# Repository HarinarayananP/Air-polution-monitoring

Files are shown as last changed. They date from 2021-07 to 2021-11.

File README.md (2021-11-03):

# Polmo - Air Pollution Monitoring System


 
 
 

POLMO is a low cost IoT based real time air pollution monitoring system. It uses advanced sensing technologies to collect pollution information from the real world sensors and provides real time data visualization, machine learning based air quality prediction, warning information for human beings, animals, and plants due to air pollution.
## Contents

- [Polmo - Air Pollution Monitoring System](#polmo---air-pollution-monitoring-system)
  - [Contents](#contents)
  - [Short description](#short-description)
    - [What's the problem?](#whats-the-problem)
    - [How can technology help?](#how-can-technology-help)
    - [The idea](#the-idea)
  - [Demo video](#demo-video)
  - [The architecture](#the-architecture)
  - [Long description](#long-description)
  - [Project roadmap](#project-roadmap)
  - [Getting started](#getting-started)
  - [Live demo](#live-demo)
  - [Applications](#applications)
    - [Mesh Network - Simple application](#mesh-network---simple-application)
    - [Mesh Network - Vehicle Traffic](#mesh-network---vehicle-traffic)
  - [Built with](#built-with)
  - [Contributing](#contributing)
  - [Authors](#authors)
  - [License](#license)
  - [Acknoledgement](#acknoledgement)

## Short description

### What's the problem?

Air pollution adversely affects human health, plant life, and agricultural crop production. Agricultural crops can be injured when exposed to high concentrations of various air pollutants. In a recent study, researchers have analysed 30 years of data on yields of wheat and rice alongside data on air pollution and climate in India and concluded that significant decreases in yield could be attributed to air pollutants.

### How can technology help?

Regular monitoring and controlling air pollution leads to increased yield from agricultural and livestock products. The warning can be given to farmers using pollution related predictions, precautions can be taken to protect plants, plan for the right cultivation time to get more yield.  There is an increased demand for localized IoT enabled automated air pollution monitoring systems which provide air pollution related information for people through an easy interface.  For realizing such a system gas sensors with advanced sensing technologies, IoT, cloud computing, and machine learning can be Incorporated.

### The idea

Developing and deploying low cost, low power, quicker, and real time air pollution monitoring system at pollution affected area. For this, array sensor nodes are developed by incorporating major air pollutants sensors and NodeMCU.  This embedded system uploads the air pollution data to the IBM Watson IoT cloud over Wi-Fi protocol. 

## Demo video

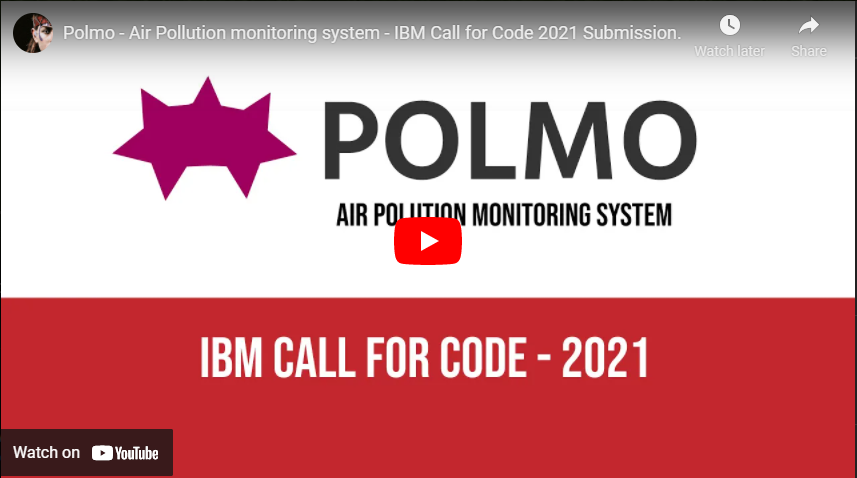
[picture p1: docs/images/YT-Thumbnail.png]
Watch the video (https://www.youtube.com/watch?v=G5Q1Tb0h1tY)


## The architecture

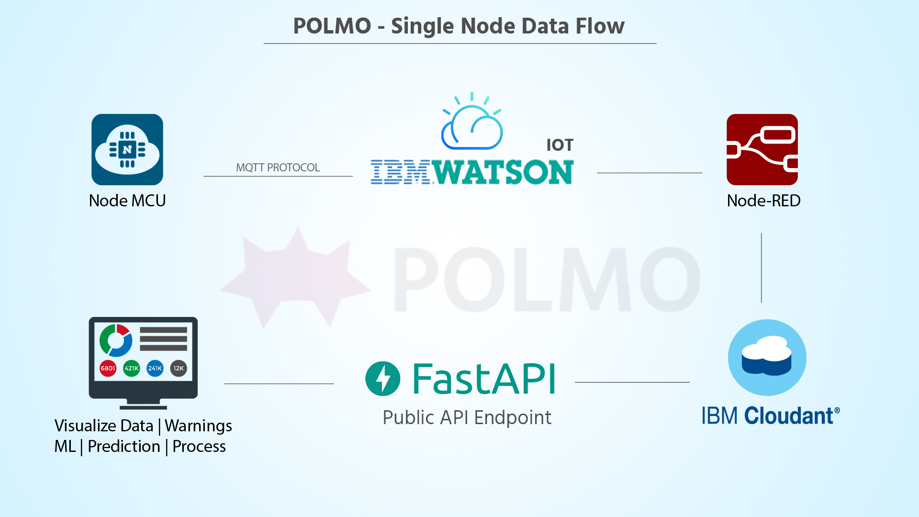
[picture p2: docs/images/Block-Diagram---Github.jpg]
Single Node Data flow


1. Node Mcu from Polmo sensor node reads the sensor readings. 
2. It will send the readings through MQTT Protocol to IBM Watson IOT
3. Using Node Red Flows the readings are fetched from IBM Watson IOT and Stored it into IBM Cloudant DB
4. A public API Endpoint is made using Fast API, It processes and delivers the contents from Cloudant DB to Apps
5. A React Dashboard is created to visualize realtime data.

## Long description

[More detail is available here](./docs/DESCRIPTION.md)

## Project roadmap

The project currently does the following things.
- Sense Major Pollutants.
- Sent readings seperatly to IBM Watson IOT cloud.
- Display Realtime data at Webendpoint
- Provide API to fetch Realtime and historical data.

See below for our past road map before Call for Code 2021 submission.

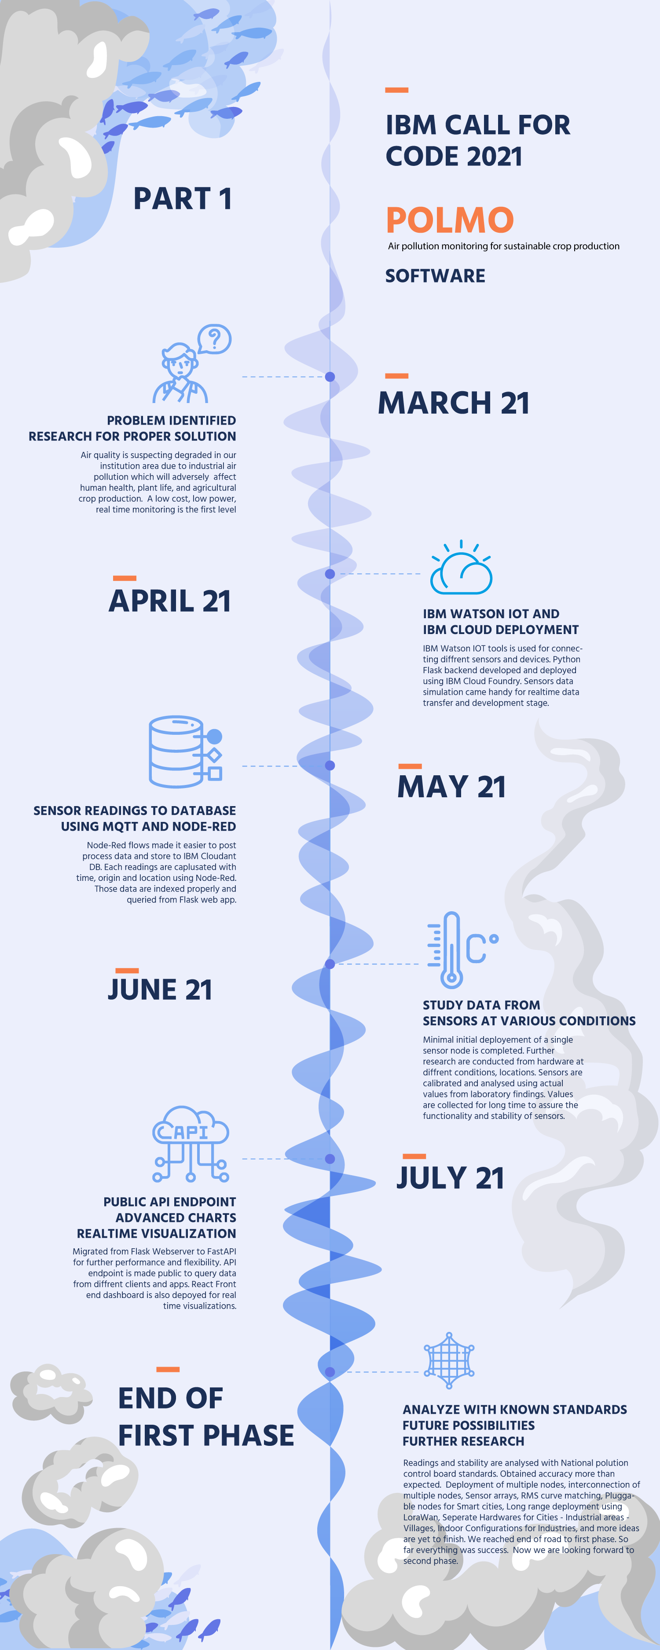
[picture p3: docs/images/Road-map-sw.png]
RoadmapSW

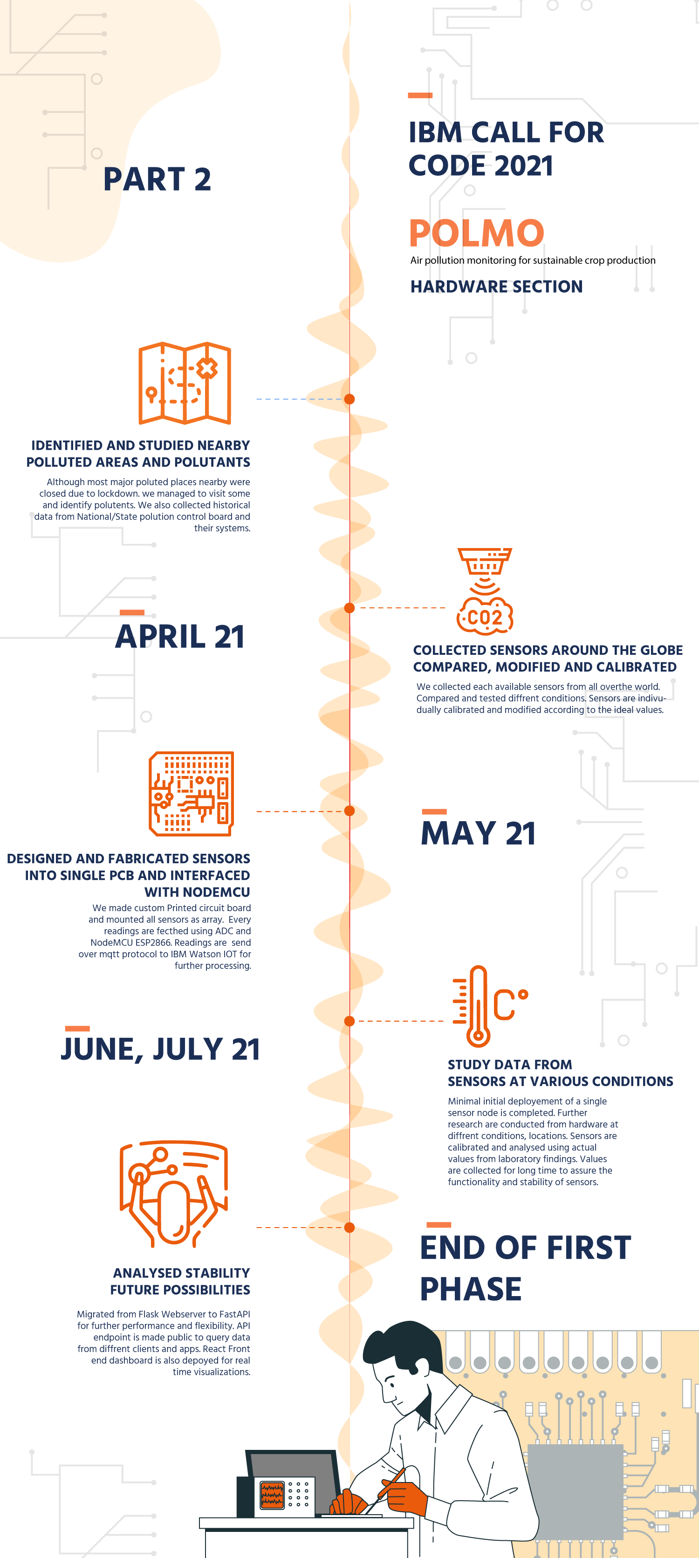
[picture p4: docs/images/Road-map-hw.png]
RoadmapHW


## Getting started

You can find the details of each section by clicking the image 🖼️ below 🔻 .

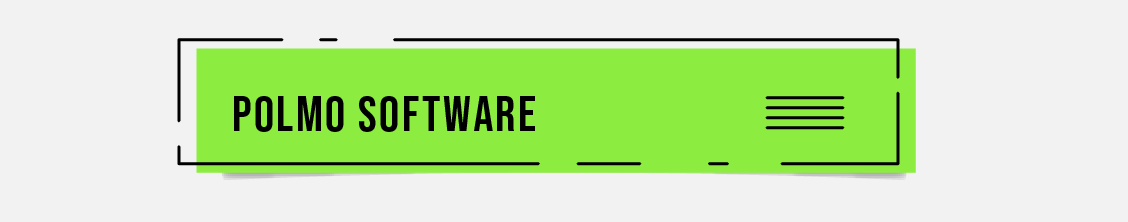
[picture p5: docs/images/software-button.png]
Polmo Software

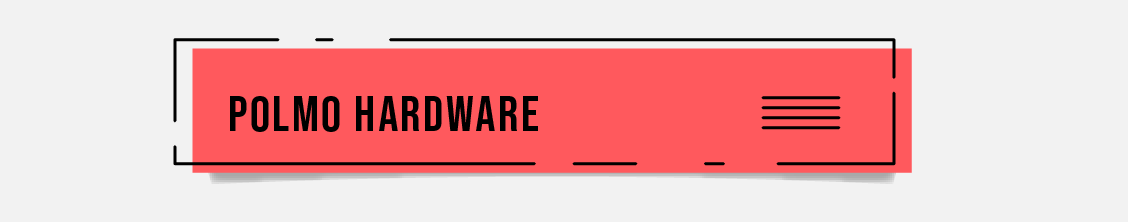
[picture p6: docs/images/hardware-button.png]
Polmo Hardware


## Live demo

By clicking this [link you](https://polmo-react-app.vercel.app/) can visit the live website. 



## Applications
Here are some animations which we are planning to build. 
### Mesh Network - Simple application
Mesh Network Plan
### Mesh Network - Vehicle Traffic
Mesh Network Application

## Built with

- [IBM Cloudant](https://cloud.ibm.com/catalog?search=cloudant#search_results) - The NoSQL database used
- [IBM Watson IOT](https://cloud.ibm.com/catalog?search=IOT#search_results) - The Internet of things platform
- [IBM Cloud Foundry](https://cloud.ibm.com/catalog?search=cloud%20foundry#search_results) - The Application Containers

## Contributing

Please read [CONTRIBUTING.md](CONTRIBUTING.md) for details on our code of conduct, and the process for submitting pull requests to us.

## Authors

<a href="https://github.com/HarinarayananP/Air-polution-monitoring/graphs/contributors">
  
</a>

- **Harinarayanan P** - [GitHub](https://github.com/HarinarayananP)
- **Amjed Ali K** - [GitHub](https://github.com/amjed-ali-k)
- **Sukhdev K** - [GitHub](https://github.com/Sukhdev)

## License

This project is licensed under the Apache 2 License - see the [LICENSE](LICENSE) file for details.

## Acknoledgement

We sincerly inform our gratitudes to
- [Sebastián Ramírez] (https://github.com/tiangolo) - For FastAPI framework
- [Creative Tim] (https://www.creative-tim.com/) - For Argon free dashboard template
- [Webkom] (https://github.com/0wczar/airframe-react) - For a beautiful react Dashboard
- [Freepik] (https://freepik.com) - For design files and templates
- All family, friends, collegues who helped and appreciated us in this journey.

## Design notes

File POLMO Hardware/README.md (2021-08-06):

# POLMO - Hardware

## Contents
- [POLMO - Hardware](#polmo---hardware)
  - [Contents](#contents)
  - [Code](#code)
  - [Hardware Photo](#hardware-photo)
  - [Designs of Multiple node](#designs-of-multiple-node)
    - [Polmo Rural node](#polmo-rural-node)
    - [Polmo Urban node](#polmo-urban-node)
    - [Indoor Closed Network Polmo node](#indoor-closed-network-polmo-node)

## Code
Node Mcu (ESP8266 1.0) code can be viewed by clicking this [link](./Node%20Mcu%20Code/mqttclient.ino).
You have to update the WiFi credentials in the code shown below.

```cpp
// WiFi Credentials
const char* ssid = "********"; // WiFi SSID
const char* password = "**************"; // WiFi Password
```
Also IBM Watson IOT configshown below.
```cpp
// IBM Watson IOT - Device Credentials
#define ORG "****" 
#define DEVICE_TYPE "*******" 
#define DEVICE_ID "****" 
#define TOKEN "**********" 

```
This code use Non-Secure data communitication. So, after updating the code, Kindly disable the security to Token Authentication on IBM Watson IOT Dashboard.

## Hardware Photo
Below shows the photo of Hardware prototype which we made for testing.
The PCB Design and Schematic Diagrams can be found [here.](/PCB%20Design%20Files)
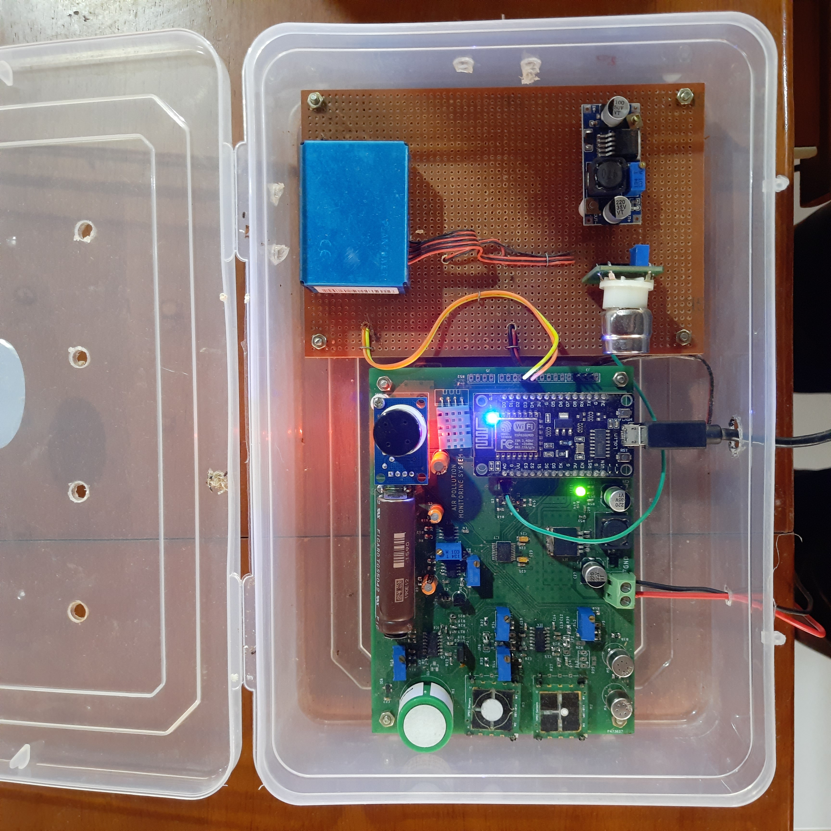
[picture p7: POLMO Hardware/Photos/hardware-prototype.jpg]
Single Node Data flow


## Designs of Multiple node
Here show multiple data flow designs for individual Polmo nodes we are going to fabricate. Currently the node connects directly to the IBM Watson IOT platform. But when we scale the nodes into multiple areas or creating a mesh network, All data flow goes through a master node. LoraWan or any other low power networks will be used to connect between Polmo End Nodes and Master nodes. Master nodes will be connected directly to IBM Watson IOT Platform.
Depending upon the type of region, envornaments we have to design and implement diffrent types of end nodes. Mainly there are 3 types of Polmo End nodes
- Polmo Rural node - For Villages, Farmlands, Green Terrains.
- Polmo Urban node - For Cities, Industiral, Crouded areas.
- Polmo Indoor node - For Homes, Factories, Large camps, Reserved areas.

### Polmo Rural node
This node is indented to deploy in less areas like villages, farmlands. There will be only limited number of deployments in a large area. Sensors will only collect data in long intervals and go to sleep mode. Long range low power communication protocols like LoRaWAN will be used to connect this nodes to its master.
<br><br>
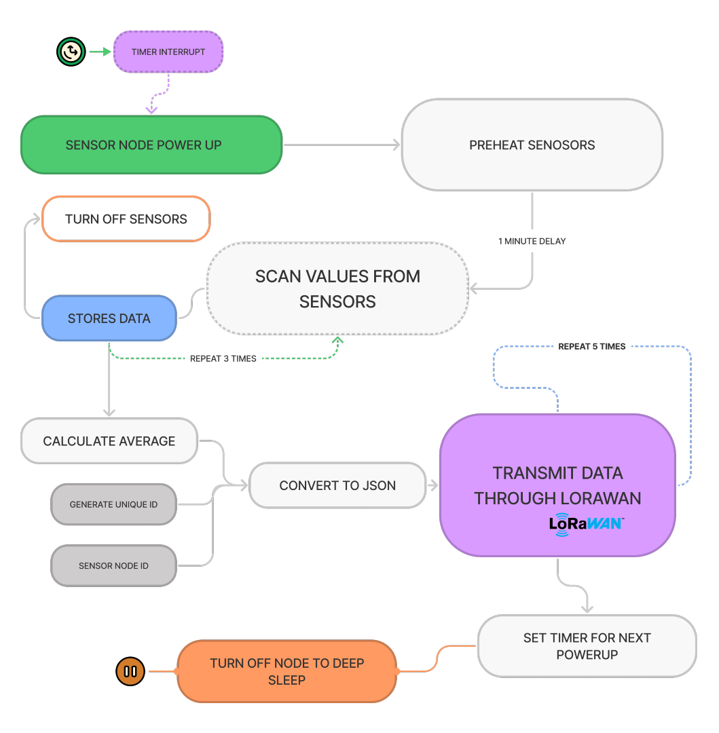
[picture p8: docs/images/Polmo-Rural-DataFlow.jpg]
Rural node data flow


### Polmo Urban node
Polmo Urban nodes will be deployed in highly populated, crouded areas where pollution will affect large number of beings. This node will fetch sensor readings in seconds and send to its master node. Urban nodes will be deployed in short range and even a single city will contains multiple nodes. Urban nodes will have much more accuracy and used to display realtime readings.
<br><br>
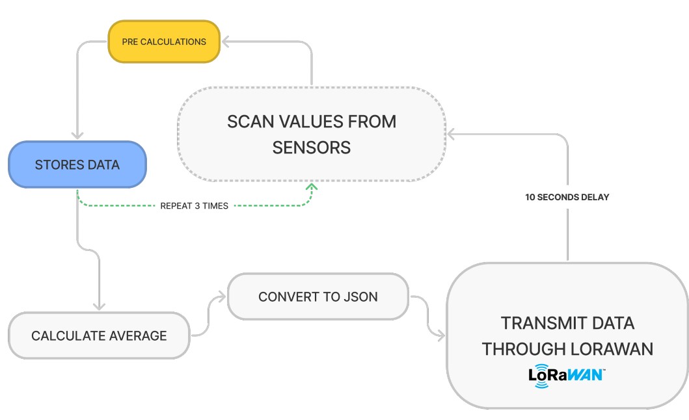
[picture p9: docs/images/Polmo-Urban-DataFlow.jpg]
Urban node data flow


### Indoor Closed Network Polmo node
Indoor nodes are made for deployment inside homes, factories and industries. It will be used for particular purposes and safety of humans in houses and the workers in factory. These nodes may not have master nodes and will be directly connected to LAN networks. 
<br><br>
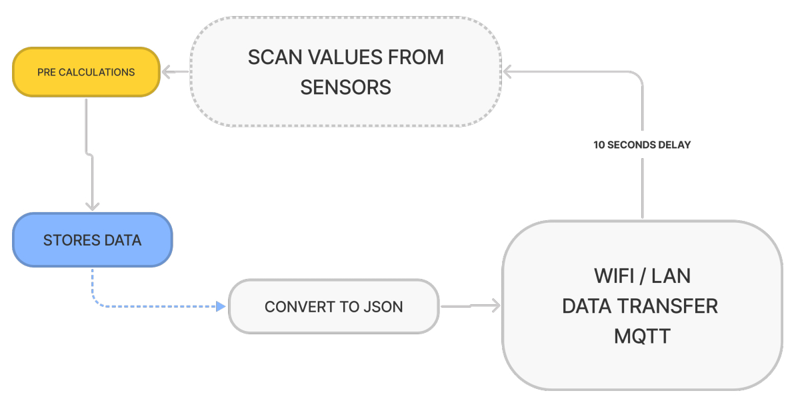
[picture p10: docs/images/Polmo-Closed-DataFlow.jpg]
Indoor node data flow


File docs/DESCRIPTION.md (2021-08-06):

### POLMO

Air pollution degrades the air quality and is a major concern all around the world for human beings and the ecosystem. Air pollution is the presence of gases, solid or liquid dust
particles called particulates, or smoke in the atmosphere which makes harms to humans, animals, plants, agricultural crops, and our environment. More than 80% of the world population lives in places where AQI (Air Quality Index) level exceeds the safe level WHO limits.
Toxic gases such as Carbon Monoxide(CO), Nitrogen Dioxide(NO₂), Sulphur Dioxide(SO₂), Ozone(O₃), Greenhouse gases such as Methane(CH₄), Carbon Dioxide(CO2), and particulate matters(tiny solid or liquid particles) namely PM2.5 and PM10 are the major air pollutants.

Agricultural crops can be injured when exposed to high concentrations of various air pollutants. Injury ranges from markings on the foliage to reduce growth, yield, and even premature death of the plant. In a recent study, researchers have analyzed 30 years of data on yields of wheat and rice alongside data on air pollution and climate change in India and concluded that significant decreases in yield could be attributed due to air pollutants. Up to 90% of the decrease in potential food production seems to be linked to air pollution while the remaining 10% link to global warming. If proper warning can be given to farmers using pollution related information and predictions, precautions can be taken to protect plants and plan for the right cultivation time. Thus, regular monitoring and controlling air pollution leads to an increase in the yield of agricultural and livestock products.

The first step to control air pollution is continuously monitoring the pollution level and comparing it with the ambient air quality standards issued by authorities. Real-time and continuous monitoring systems are the new trends in air quality monitoring globally. CAAQMS (Continuous Ambient Air Quality Monitoring Stations) uses gas analyzers and is housed in a temperature controlled room. It is implemented on loT Technology for automatic data collection to the central server. But it is very costly to install and maintain and thus not suitable for dense deployment. The air quality changes drastically over hundreds of metres, and therefore localized low cost systems for air pollution monitoring are required. Sensor-loT-Cloud based design is a good solution to solve this problem.
Thus, we developed a low-cost, low-power, and portable cloud-based real-time air pollution monitoring system, “POLMO” over IBM cloud service platform intended to deploy in farmland areas to give pollution related information to farmers for sustainable crop production.

“IBM Watson” loT toos is used for connecting different sensors and devices. Python “Flask” is developed and deployed using IBM cloud foundry. Node-Red flows made it easier to post, process data and store to IBM cloudantDB. Each reading is capsulated with time, origin and location ID using Node-Red. Initially, sensor nodes with a single sensor unit are deployed and data are observed continuously for a long period to ensure the functionality and stability of sensors. ESP8266 based NodeMCU is used in the sensor node to collect and send the sensor data to the cloud server over Wi-Fi. Field level clean air calibration is conducted for
measurement accuracy. Later an array sensor node is designed, developed, and fabricated by integrating 11 sensors and a NodeMCU as a single embedded system to use as an loT end device. Public API endpoint is made using fast API for the public to query data from different clients and apps. React.js dashboard provides real time sensor data visualization. The data collected are compared and analyzed with the National Pollution Control Board standards and obtained accuracy more than that expected.

We reached the end of the road of the first phase of the “POLMO” project. So far everything was a success. Now we are looking forward to the second phase by deploying multiple array sensor nodes over a large geographical area by wide-area deployment and wireless interconnection of multiple nodes using low power WAN, development of pluggable sensor nodes in smart city networks, development of separate hardware for urban, rural, and industrial areas, indoor configuration for industries, and much more are our future plans.

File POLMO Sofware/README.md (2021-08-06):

# POLMO - Software
## Table of contents
- [POLMO - Software](#polmo---software)
  - [Table of contents](#table-of-contents)
  - [Polmo API Endpoint - FastAPI](#polmo-api-endpoint---fastapi)
    - [Visit API Endpoints Documentation](#visit-api-endpoints-documentation)
  - [Polmo Dashboard - React JS](#polmo-dashboard---react-js)
    - [Demo Login](#demo-login)
  - [Polmo Full WebApp - Flask webserver (Discontinued)](#polmo-full-webapp---flask-webserver-discontinued)

## Polmo API Endpoint - FastAPI
We used Fast API to get data from IBM Cloudant DB to public. Currently API Endpoint will only fetch realtime data, which is used to display on the dashboard. API Will be expanded and provided much more data fetching options. We also use a simple user database and support user registration and login using API Endpoint. JWT Authentication is used for session management.
<br />
Fast API is currently the fastest API app with validation. Sample code is uploaded [here](./Fast%20API%20-%20Backend/).







### Visit API Endpoints Documentation




## Polmo Dashboard - React JS
For realtime data visualization we made a dashboard using React framework. It will send API calls to the FastAPI backend and displays data realtime. Dashboard work is still in progress. Currently it only displays on Polmo Sensor node.






### Demo Login
username: `test`
password: `test`

## Polmo Full WebApp - Flask webserver (Discontinued)
When the time of testing and collecting bulk data from Polmo Sensor node, we used a Flask webserver and Jinja Templating engine for displaying data. This was made for temporary use for analysing data.

Code Archive is [uploaded here](Flask%20Web%20server%20-%20Old/)

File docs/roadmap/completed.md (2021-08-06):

#  Roadmap - Finished
RoadmapSW
RoadmapHW

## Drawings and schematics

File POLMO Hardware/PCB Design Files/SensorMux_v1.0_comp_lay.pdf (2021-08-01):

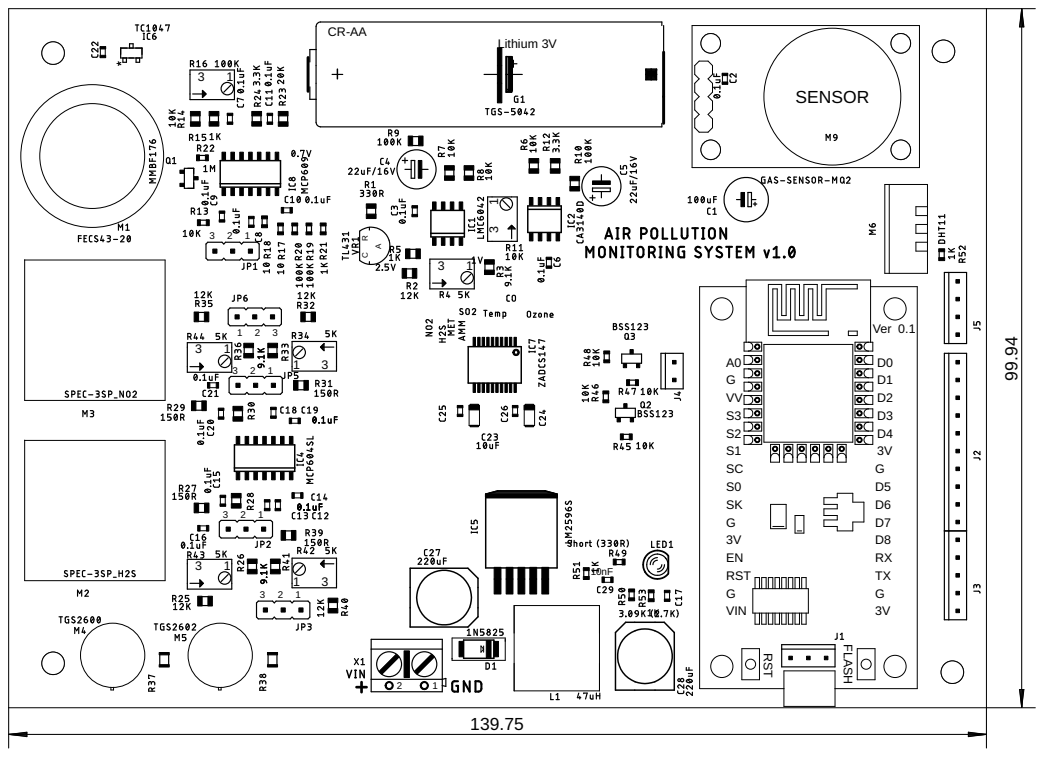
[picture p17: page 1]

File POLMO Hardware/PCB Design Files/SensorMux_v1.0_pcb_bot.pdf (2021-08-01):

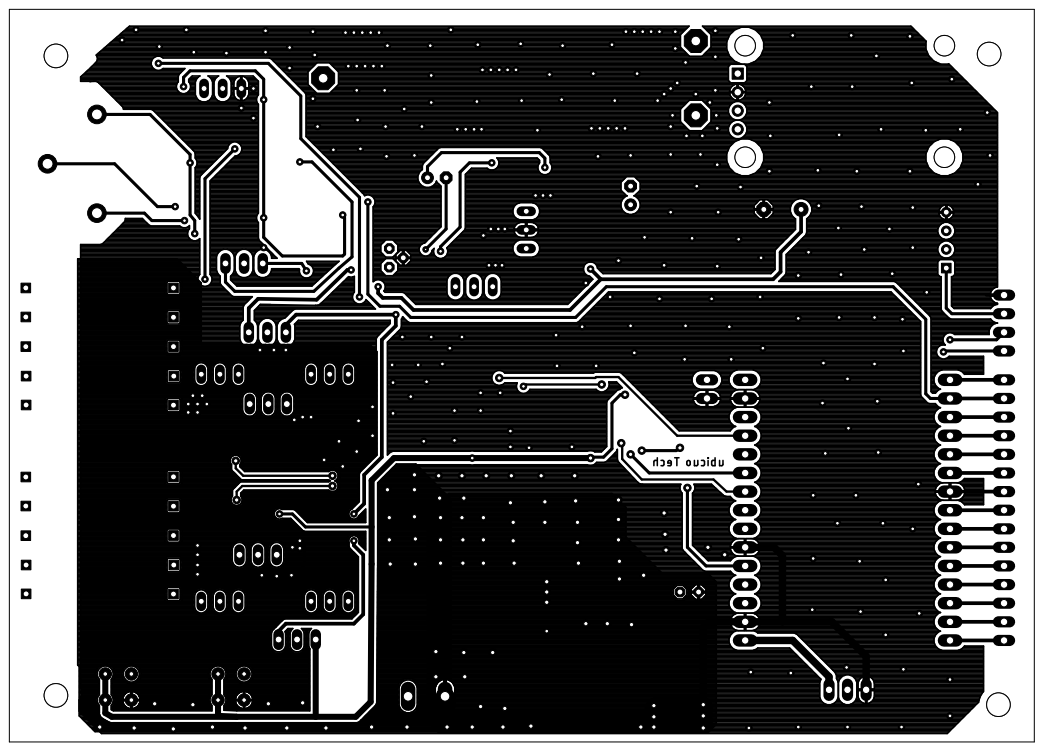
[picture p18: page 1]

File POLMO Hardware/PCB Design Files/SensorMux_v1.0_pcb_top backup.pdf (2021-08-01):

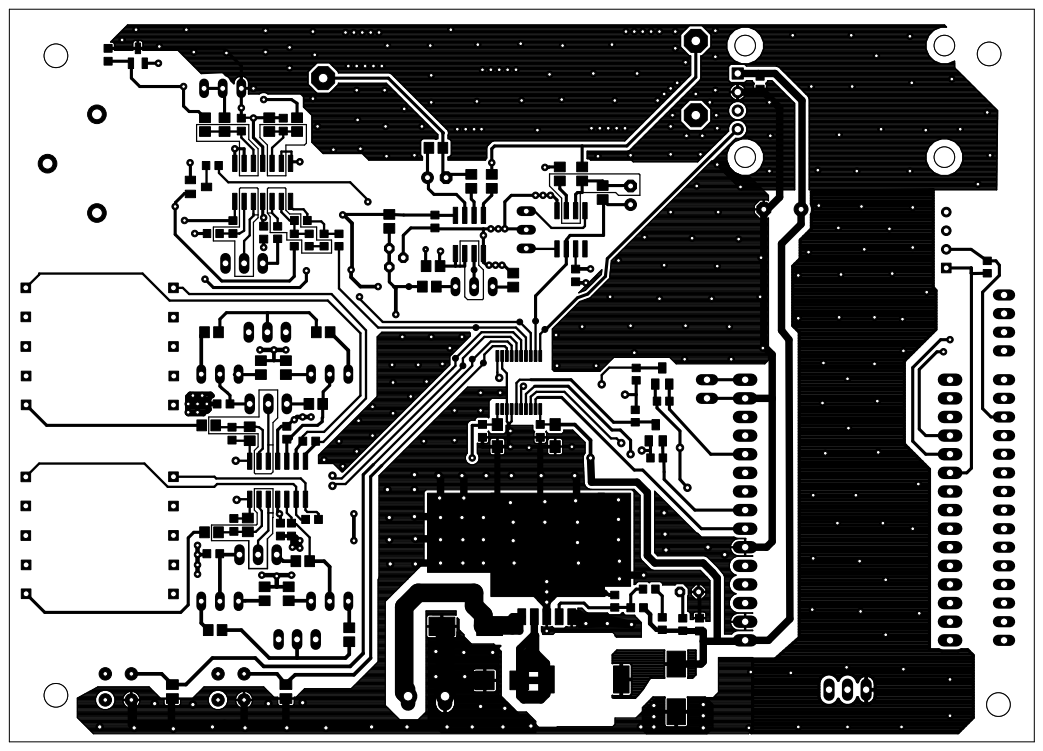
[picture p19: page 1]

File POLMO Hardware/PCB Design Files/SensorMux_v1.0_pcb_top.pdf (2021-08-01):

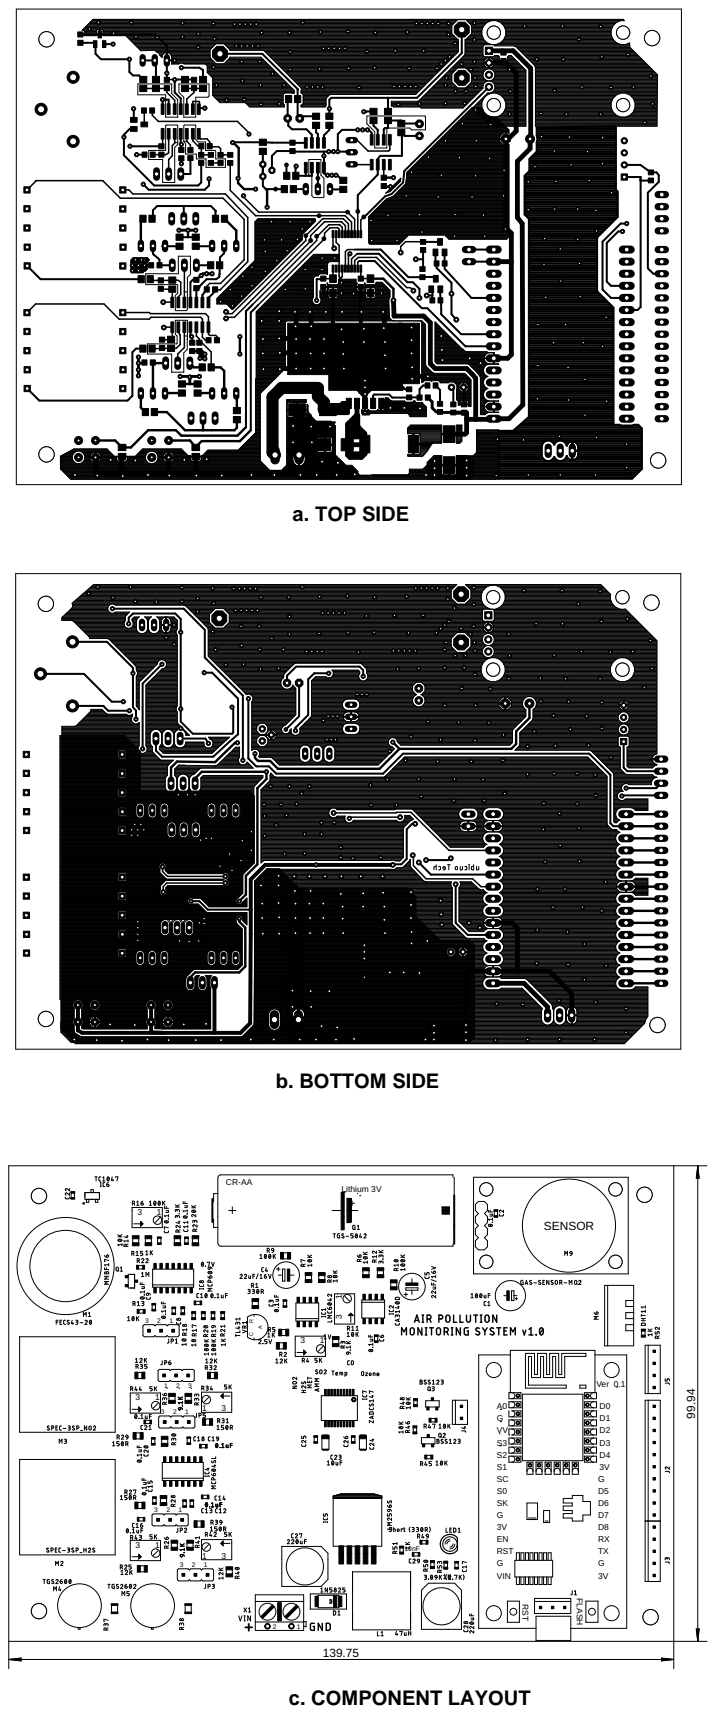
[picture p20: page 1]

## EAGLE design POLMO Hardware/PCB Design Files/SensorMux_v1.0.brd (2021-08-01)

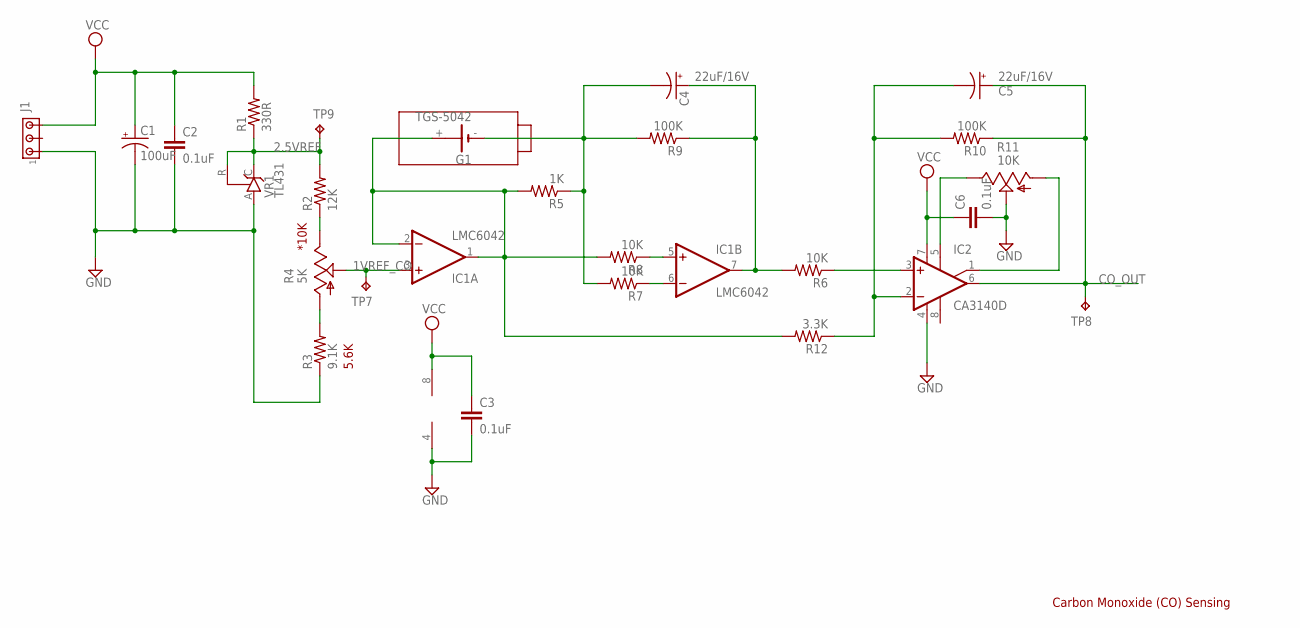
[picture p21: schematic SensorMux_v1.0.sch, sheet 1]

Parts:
C1: 100uF; E5-6
C2, C3, C6: 0.1uF; C0603K
C4, C5: 22uF/16V; E2,5-6
G1: TGS-5042; CRAA
IC1: LMC6042; SO08
IC2: CA3140D; SO08
J1: MTA03-100; 10X03MTA
R1: 330R; R0805
R2: 12K; R0805
R3: 9.1K; R0805
R4: 5K; B64Y
R5: 1K; R0805
R6, R7, R8: 10K; R0805
R9, R10: 100K; R0805
R11: 10K; B64Y
R12: 3.3K; R0805
TP7: 1V; TP08R
TP8: CO; TP08R
TP9: 2.5V; TP08R
VR1: TL431; TO92-CLP

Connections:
1VREF_CO: IC1.3 (+IN), R4.S, TP7.TP
2.5VREF: R1.1, R2.2, TP9.TP, VR1.C, VR1.R; also elsewhere on the board
CO_OUT: C5.+, IC2.6 (OUT), R10.1, TP8.TP; also elsewhere on the board
GND: C1.-, C2.2, C3.2, C6.2, IC1.4 (V-), IC2.4 (V-), J1.1, R3.1, R11.S, VR1.A; also elsewhere on the board
unnamed: G1.+, IC1.1 (OUT), IC1.2 (-IN), R5.2, R8.2, R12.2
unnamed: IC1.6 (-IN), R7.1
unnamed: C4.-, G1.-, R5.1, R7.2, R9.2
unnamed: IC1.5 (+IN), R8.1
unnamed: R2.1, R4.E
unnamed: R3.2, R4.A
unnamed: C4.+, IC1.7 (OUT), R6.2, R9.1
unnamed: IC2.3 (+IN), R6.1
unnamed: C5.-, IC2.2 (-IN), R10.2, R12.1
unnamed: IC2.5 (ON), R11.E
unnamed: IC2.1 (ON/CMP), R11.A
VCC: C1.+, C2.1, C3.1, C6.1, IC1.8 (V+), IC2.7 (V+), J1.3, R1.2; also elsewhere on the board

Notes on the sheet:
Carbon Monoxide (CO) Sensing
5.6K
*10K

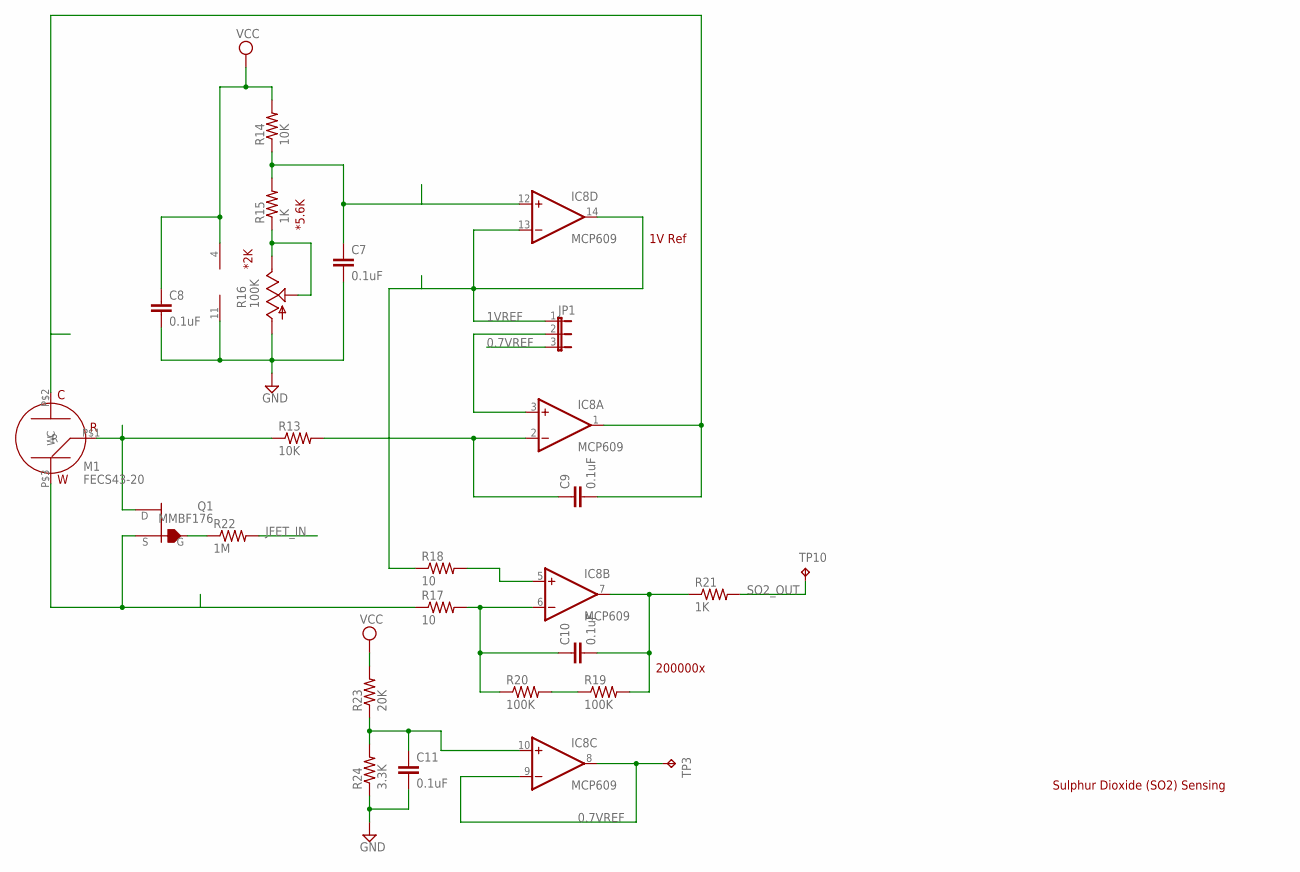
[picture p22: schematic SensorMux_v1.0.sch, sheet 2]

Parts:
C7, C8, C9, C10, C11: 0.1uF; C0603K
IC8: MCP609; SO14
JP1: JP2E; JP2
M1: FECS43-20; FECS43
Q1: MMBF176; SOT23
R13: 10K; R0603
R14: 10K; R0805
R15: 1K; R0805
R16: 100K; B64Y
R17, R18: 10; R0603
R19, R20: 100K; R0603
R21: 1K; R0603
R22: 1M; R0603
R23: 20K; R0805
R24: 3.3K; R0805
TP3: 0.7V; TP08R
TP10: SO2; TP08R

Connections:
0.7V: C11.1, IC8.10 (+IN), R23.1, R24.2
0.7VREF: IC8.8 (OUT), IC8.9 (-IN), JP1.3, TP3.TP
1VREF: IC8.13 (-IN), IC8.14 (OUT), JP1.1, R18.1
GND: C7.2, C8.2, C11.2, IC8.11 (V-), R16.A, R24.1; also elsewhere on the board
JFET_IN: R22.2; also elsewhere on the board
unnamed: C9.1, IC8.2 (-IN), R13.2
unnamed: M1.P$1 (R), Q1.1 (D), R13.1
unnamed: C9.2, IC8.1 (OUT), M1.P$2 (C)
unnamed: R15.1, R16.E, R16.S
unnamed: R19.1, R20.2
unnamed: C7.1, IC8.12 (+IN), R14.1, R15.2
unnamed: IC8.3 (+IN), JP1.2
unnamed: C10.1, IC8.6 (-IN), R17.2, R20.1
unnamed: IC8.5 (+IN), R18.2
unnamed: M1.P$3 (W), Q1.2 (S), R17.1
unnamed: C10.2, IC8.7 (OUT), R19.2, R21.1
unnamed: Q1.3 (G), R22.1
SO2_OUT: R21.2, TP10.TP; also elsewhere on the board
VCC: C8.1, IC8.4 (V+), R14.2, R23.2; also elsewhere on the board

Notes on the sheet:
1V Ref
200000x
Sulphur Dioxide (SO2) Sensing
*5.6K
*2K

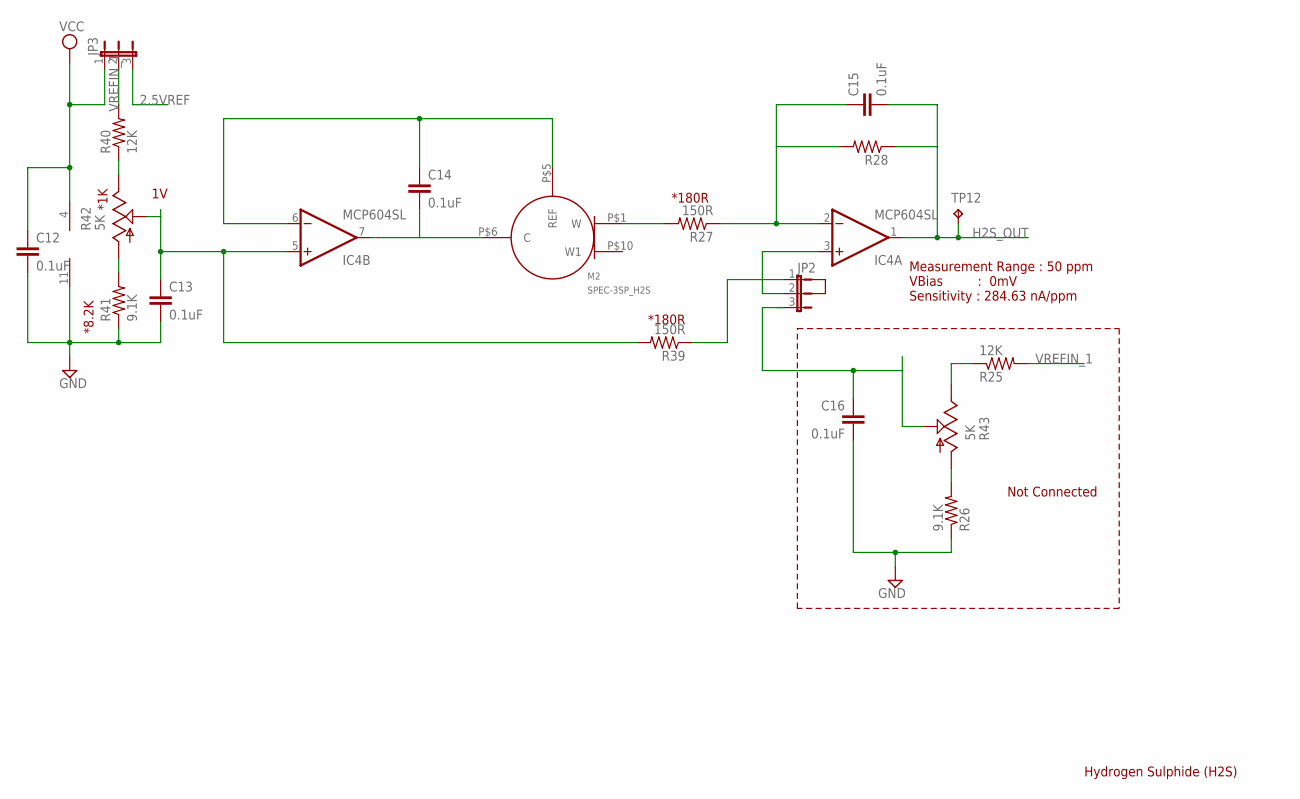
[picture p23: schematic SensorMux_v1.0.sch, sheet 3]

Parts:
C12, C13, C14, C15, C16: 0.1uF; C0603K
IC4: MCP604SL; SO14
JP2, JP3: JP2E; JP2
M2: SPEC-3SP_H2S; SPEC-3SP
R25, R40: 12K; R0805
R26, R41: 9.1K; R0805
R27, R39: 150R; R0805
R28: R-US_R0805; R0805
R42, R43: 5K; B64Y
TP12: H2S; TP08R

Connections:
2.5VREF: JP3.3; also elsewhere on the board
GND: C12.2, C13.2, C16.2, IC4.11 (V-), R26.1, R41.1; also elsewhere on the board
H2S_OUT: C15.2, IC4.1 (OUT), R28.1, TP12.TP; also elsewhere on the board
unnamed: C14.1, IC4.6 (-IN), M2.P$5 (REF)
unnamed: C14.2, IC4.7 (OUT), M2.P$6 (C)
unnamed: C13.1, IC4.5 (+IN), R39.2, R42.S
unnamed: M2.P$1 (W), R27.2
unnamed: C15.1, IC4.2 (-IN), R27.1, R28.2
unnamed: C16.1, JP2.3, R43.S
unnamed: IC4.3 (+IN), JP2.2
unnamed: R25.1, R43.E
unnamed: R26.2, R43.A
unnamed: JP2.1, R39.1
unnamed: R40.1, R42.E
unnamed: R41.2, R42.A
VCC: C12.1, IC4.4 (V+), JP3.1; also elsewhere on the board
VREFIN_1: JP3.2, R25.2, R40.2

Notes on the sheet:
Hydrogen Sulphide (H2S)
Measurement Range : 50 ppm VBias : 0mV Sensitivity : 284.63 nA/ppm
*180R
*8.2K
*1K
Not Connected

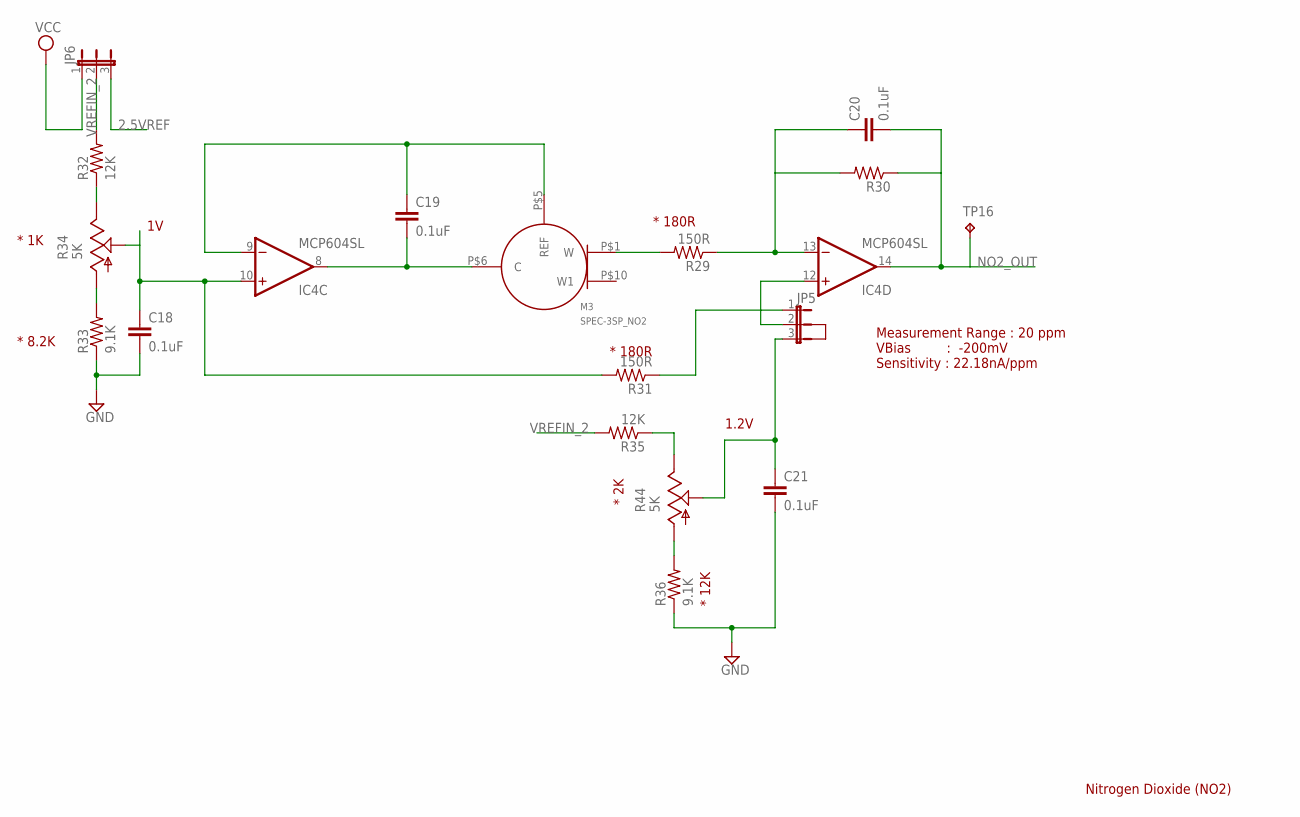
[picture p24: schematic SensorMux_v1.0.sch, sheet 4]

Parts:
C18, C19, C20, C21: 0.1uF; C0603K
IC4: MCP604SL; SO14
JP5, JP6: JP2E; JP2
M3: SPEC-3SP_NO2; SPEC-3SP
R29, R31: 150R; R0805
R30: R-US_R0805; R0805
R32, R35: 12K; R0805
R33, R36: 9.1K; R0805
R34, R44: 5K; B64Y
TP16: NO2; TP08R

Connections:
2.5VREF: JP6.3; also elsewhere on the board
GND: C18.2, C21.2, R33.1, R36.1; also elsewhere on the board
unnamed: C19.1, IC4.9 (-IN), M3.P$5 (REF)
unnamed: C19.2, IC4.8 (OUT), M3.P$6 (C)
unnamed: C18.1, IC4.10 (+IN), R31.2, R34.S
unnamed: M3.P$1 (W), R29.2
unnamed: C20.1, IC4.13 (-IN), R29.1, R30.2
unnamed: C21.1, JP5.3, R44.S
unnamed: IC4.12 (+IN), JP5.2
unnamed: JP5.1, R31.1
unnamed: R32.1, R34.E
unnamed: R33.2, R34.A
unnamed: R35.1, R44.E
unnamed: R36.2, R44.A
NO2_OUT: C20.2, IC4.14 (OUT), R30.1, TP16.TP; also elsewhere on the board
VCC: JP6.1; also elsewhere on the board
VREFIN_2: JP6.2, R32.2, R35.2

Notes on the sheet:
Nitrogen Dioxide (NO2)
Measurement Range : 20 ppm VBias : -200mV Sensitivity : 22.18nA/ppm
* 1K
* 8.2K
* 12K
* 2K
1.2V
* 180R

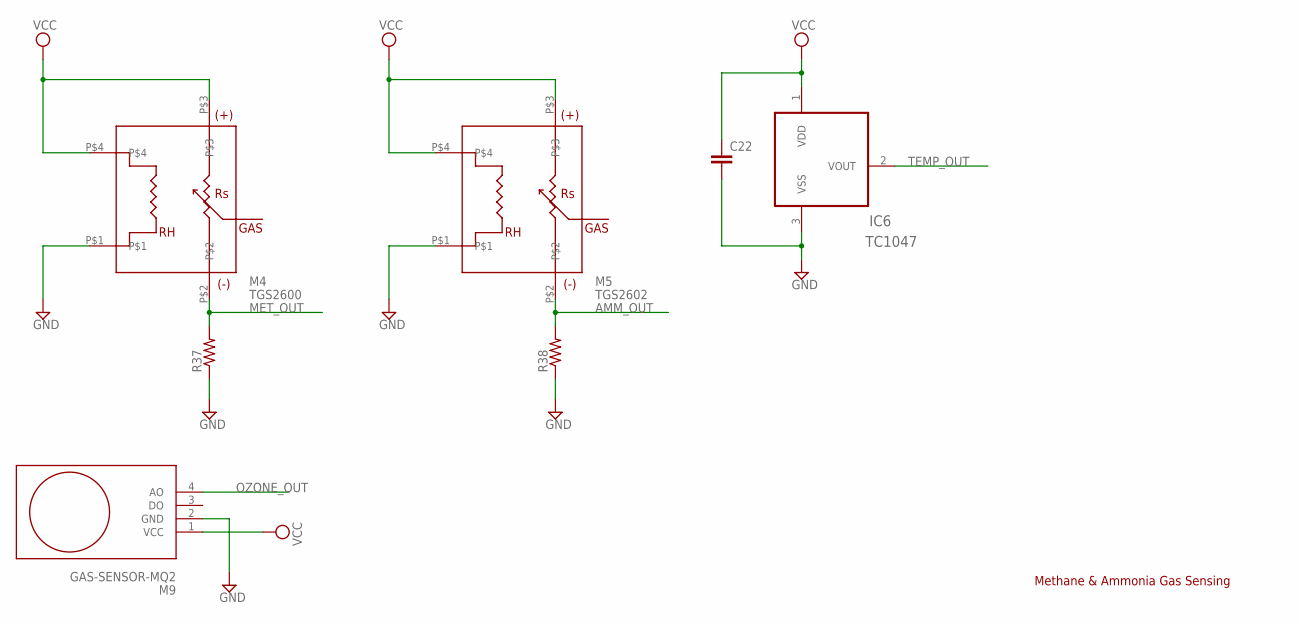
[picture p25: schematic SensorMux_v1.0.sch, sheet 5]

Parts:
C22: C-EUC0603K; C0603K
IC6: TC1047; SOT95P237X112-3N
M4: TGS2600; TGS26XX
M5: TGS2602; TGS26XX
M9: GAS-SENSOR-MQ2
R37, R38: R-US_M0805; M0805

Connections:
AMM_OUT: M5.P$2, R38.2; also elsewhere on the board
GND: C22.2, IC6.3 (VSS), M4.P$1, M5.P$1, M9.2 (GND), R37.1, R38.1; also elsewhere on the board
MET_OUT: M4.P$2, R37.2; also elsewhere on the board
OZONE_OUT: M9.4 (AO); also elsewhere on the board
TEMP_OUT: IC6.2 (VOUT); also elsewhere on the board
VCC: C22.1, IC6.1 (VDD), M4.P$3, M4.P$4, M5.P$3, M5.P$4, M9.1 (VCC); also elsewhere on the board

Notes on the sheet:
Methane & Ammonia Gas Sensing

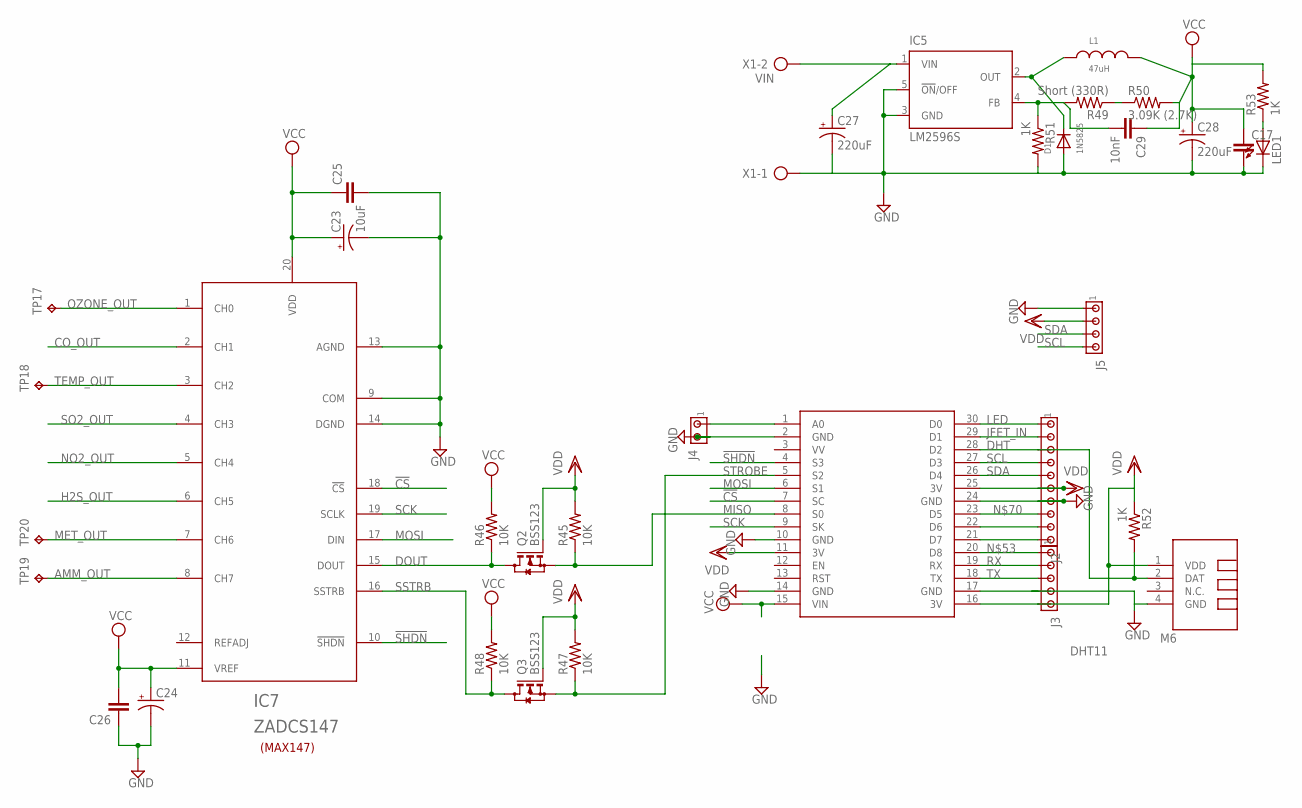
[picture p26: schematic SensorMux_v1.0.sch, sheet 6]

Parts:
C17, C25, C26: C-EUC0603K; C0603K
C23: 10uF; SMC_A
C24: CPOL-USSMCA; SMC_A
C27, C28: 220uF; 140CLH-0810
C29: 10nF; C0603K
D1: 1N5825; SMADIODE
IC5: LM2596S; TO263-5
IC7: ZADCS147; SSOP20
J2: MTA10-100; 10X10MTA
J3: MTA05-100; 10X05MTA
J4: MTA02-100; 10X02MTA
J5: MTA04-100; 10X04MTA
L1: 47uH; WE-CHSA_1212
LED1: LED3MM
M6: DHT11; TEMP-HUM-SENSOR-DHT11
M8: NODEMCU
Q2, Q3: BSS123; SOT23
R45, R46, R47, R48: 10K; R0603
R49: Short (330R); R0603
R50: 3.09K (2.7K); R0603
R51, R52, R53: 1K; R0603
TP17: Ozone; TP08R
TP18: Temp; TP08R
TP19: AMM; TP08R
TP20: MET; TP08R
X1: VIN; AK500/2

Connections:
!CS: IC7.18 (!CS), M8.7 (SC)
!SHDN: IC7.10 (!SHDN), M8.4 (S3)
AMM_OUT: IC7.8 (CH7), TP19.TP; also elsewhere on the board
CO_OUT: IC7.2 (CH1); also elsewhere on the board
DHT: J2.3, M6.2 (DAT), M8.28 (D2), R52.2
DOUT: IC7.15 (DOUT), Q2.3 (D), R46.1
GND: C17.2, C23.-, C24.-, C25.2, C26.1, C27.-, C28.-, D1.A, IC5.3 (GND), IC5.5 (!ON!/OFF), IC7.9 (COM), IC7.13 (AGND), IC7.14 (DGND), J2.7, J4.2, J5.1, LED1.K (C), M6.4 (GND), M8.2 (GND), M8.10 (GND), M8.14 (GND), M8.24 (GND), R51.2, X1.1; also elsewhere on the board
H2S_OUT: IC7.6 (CH5); also elsewhere on the board
JFET_IN: J2.2, M8.29 (D1); also elsewhere on the board
LED: J2.1, M8.30 (D0)
MET_OUT: IC7.7 (CH6), TP20.TP; also elsewhere on the board
MISO: M8.8 (S0), Q2.2 (S), R45.1
MOSI: IC7.17 (DIN), M8.6 (S1)
unnamed: J3.1, M8.20 (D8)
unnamed: LED1.A, R53.1
unnamed: R49.1, R50.1
unnamed: J2.8, M8.23 (D5)
unnamed: J2.9, M8.22 (D6)
unnamed: J2.10, M8.21 (D7)
unnamed: J3.4, M8.17 (GND)
unnamed: J4.1, M8.1 (A0)
NO2_OUT: IC7.5 (CH4); also elsewhere on the board
OUT: D1.C, IC5.2 (OUT), L1.1
OZONE_OUT: IC7.1 (CH0), TP17.TP; also elsewhere on the board
RX: J3.2, M8.19 (RX)
SCK: IC7.19 (SCLK), M8.9 (SK)
SCL: J2.4, J5.4, M8.27 (D3)
SDA: J2.5, J5.3, M8.26 (D4)
SO2_OUT: IC7.4 (CH3); also elsewhere on the board
SSTRB: IC7.16 (SSTRB), Q3.3 (D), R48.1
STROBE: M8.5 (S2), Q3.2 (S), R47.1
TEMP_OUT: IC7.3 (CH2), TP18.TP; also elsewhere on the board
TX: J3.3, M8.18 (TX)
VCC: C17.1, C23.+, C24.+, C25.1, C26.2, C28.+, C29.1, IC7.11 (VREF), IC7.20 (VDD), L1.2, M8.15 (VIN), R46.2, R48.2, R50.2, R53.2; also elsewhere on the board
VDD: J2.6, J3.5, J5.2, M6.1 (VDD), M8.11 (3V), M8.16 (3V), M8.25 (3V), Q2.1 (G), Q3.1 (G), R45.2, R47.2, R52.1
VFBK: C29.2, IC5.4 (FB), R49.2, R51.1
VIN: C27.+, IC5.1 (VIN), X1.2

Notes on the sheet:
(MAX147)

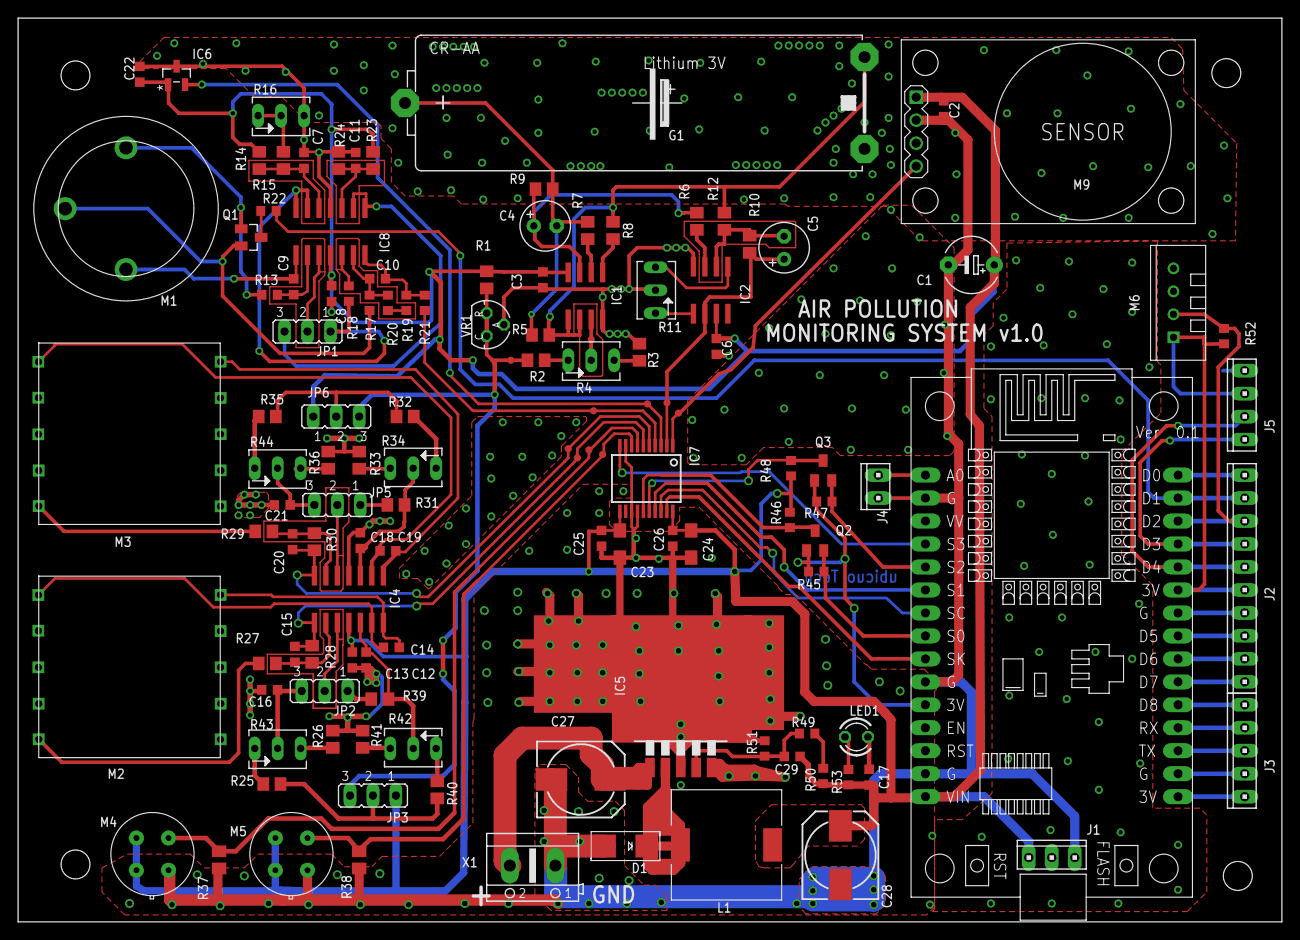
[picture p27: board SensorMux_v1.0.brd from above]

Board: 2 copper layers, 139.8 x 99.9 mm, 127 parts (0 on the bottom side), 91 nets.

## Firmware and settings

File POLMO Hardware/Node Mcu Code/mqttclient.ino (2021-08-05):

#define DHTPIN   D2
#define STEPSIZE 1.22E-03
#define LED D0
#define DHTTYPE DHT11

#include <ESP8266WiFi.h>
#include <PubSubClient.h>
#include <WiFiUdp.h>
#include "PMS.h"
#include "SoftwareSerial.h"
#include "ADC_MAX147.h"
#include <Adafruit_Sensor.h>
#include <DHT.h>
#include <DHT_U.h>
#include "CO2Sensor.h"

float humidity, temperature;
enum channels {oz_ch = 0, temp_ch, no2_ch, met_ch, co_ch, so2_ch, h2s_ch, amm_ch};
float getEnvCorrectRatio(float,float);


// WiFi Credentials
const char* ssid = "********"; // WiFi SSID
const char* password = "**************"; // WiFi Password

// IBM Watson IOT - Device Credentials
#define ORG "****" 
#define DEVICE_TYPE "*******" 
#define DEVICE_ID "****" 
#define TOKEN "**********" 


char server[] = ORG ".messaging.internetofthings.ibmcloud.com";
char authMethod[] = "use-token-auth";
char token[] = TOKEN;
char clientId[] = "d:" ORG ":" DEVICE_TYPE ":" DEVICE_ID;


long lastMsg = 0;
char msg[150];
int loop_count = 0;

WiFiClient espClient;

SoftwareSerial Serial2(D3, D4); // RX, TX

DHT_Unified dht(DHTPIN, DHTTYPE);
ADCmax147 zadcs147(SS);

PMS pms(Serial2);
PMS::DATA data;

CO2Sensor co2Sensor(A0, 0.99, 100);



void callback(char* topic, byte* payload, unsigned int length) {
  Serial.print("Message arrived [");
  Serial.print(topic);
  Serial.print("] ");
  for (int i = 0; i < length; i++) {
    Serial.print((char)payload[i]);
  }
  Serial.println();
}

PubSubClient client(server, 1883, callback, espClient); //set MQTT port number to 8883 as per //standard


// Connect to WIFI.
void setup_wifi() {
  delay(10);
  // We start by connecting to a WiFi network
  espClient.setBufferSizes(512, 512);
  Serial.println();
  Serial.print("Connecting to ");
  Serial.println(ssid);

  WiFi.begin(ssid, password);
  // Wait until WIFI Connection is established.
  while (WiFi.status() != WL_CONNECTED) {
    delay(500);
    Serial.print(".");
  }
  Serial.println("");
  Serial.print("WiFi connected! IP address: ");
  Serial.println(WiFi.localIP());
}

// Connect to MQTT and Loop Until Connection establishes. 
void reconnect() {
  // Loop until we're reconnected
  while (!client.connected()) {
    Serial.print("Attempting MQTT connection...");
    // Attempt to connect
    if (client.connect(clientId, authMethod, token)) {
      Serial.println("Connected!");
      // Device Connected log MQTT Publish goes here..
    } else {
      Serial.print("Connection Failed :x | RC:");
      Serial.print(client.state());
      Serial.println("Retrying in 5 seconds...");

      char buf[256];
      espClient.getLastSSLError(buf, 256);
      Serial.print("WiFiClientSecure SSL error: ");
      Serial.println(buf);
      // Wait 5 seconds before retrying
      delay(5000);
    }
  }
}

void setup() {
  Serial.println("Initialising...");
  Serial.begin(9600);
  Serial.setDebugOutput(true);
  // initialize digital pin LED_BUILTIN as an output.
  pinMode(LED_BUILTIN, OUTPUT);
  setup_wifi();
  Serial.print("Heap: "); Serial.println(ESP.getFreeHeap());
  Serial2.begin(9600);
  Serial.println("Final steps...");
  SPI.begin();
  Serial.print(" 1");
  SPI.beginTransaction(SPISettings(3000000, MSBFIRST, SPI_MODE0));
  Serial.print(" 2");
  zadcs147.begin();
  Serial.print(" 3");
  co2Sensor.calibrate();
  Serial.println("Initialisation Completed.");
}

void loop() {

  // Verify MQTT Connection
  if (!client.connected()) {
    reconnect();
  }
  client.loop();
  

  Serial.println("Waiting to read data from PM Sensors...");
  while(!pms.read(data));

  /*=========================================
  1. Temperature Sense TC1047
  Sensitivity 10mV/*C  and 500mV at 0*C  
  ==========================================*/
  unsigned int adc_result = zadcs147.ADC_readch(temp_ch);
  float temp = (float)(adc_result * (STEPSIZE-(212E-06)));   // Calibration Factor
  temp = (temp - 0.5) / 0.01;
  Serial.print(adc_result);
  Serial.print("\t");
  Serial.print("Temp: ");
  Serial.println(temp,2);
  publish_data(temp, "temp");

  /*=========================================
  2. NO2 Sense SPEC-3SP-NO2
  Sense Range 20ppm, VBias : -200mV ; Sensitivity: 22.18nA/ppm
  Gas Concentration Cx(ppm) = (Vgas - Vgas0)/M
  Vgas= V out at gas level; Vgas0 = V out @ 0 gas level; Sensor Calibration Factor M (V/ppm)
  M = Sensitivity_code(nA/ppm) x TIA Gain(kV/A) x 10E-9(A/nA) x 10E03(V/KV)
  M =  22.18x499x10e-09x10e03 = 0.0110678  
  ==========================================*/
  adc_result = zadcs147.ADC_readch(no2_ch);
  Serial.print(adc_result);
  float Vgas = (float)(adc_result * STEPSIZE);
  Serial.print("\t Vgas=");
  Serial.print(Vgas,4);
  float Vgas0 = 0.9685;     // Need to get from 0 ppm Calibration Environment; now given as Vref+Voff
  float no2 = (Vgas-Vgas0)*(90.352)*0.05*0.333;
   no2 = no2*1000;
  Serial.print("\t");
  Serial.print("NO2 ppb: ");
  if(no2 < 0.0)
    no2 *= -1.0;
  Serial.println(no2,3);
  publish_data(no2, "no2");  

  /*=========================================
  3. H2S Sense SPEC-3SP-H2S
  Sense Range 50ppm, VBias : 0mV ; Sensitivity: 284.63nA/ppm
  Gas Concentration Cx(ppm) = (Vgas - Vgas0)/M
  Vgas= V out at gas level; Vgas0 = V out @ 0 gas level; Sensor Calibration Factor M (V/ppm)
  M = Sensitivity_code(nA/ppm) x TIA Gain(kV/A) x 10E-9(A/nA) x 10E03(V/KV)
  M =  284.63 x 49.9 x 10e-09 x 10e03 = 0.014203  ;
  ==========================================*/
  adc_result = zadcs147.ADC_readch(h2s_ch);
  Serial.print(adc_result);
  Vgas = (float)(adc_result * STEPSIZE);
  Serial.print("\t Vgas=");
  Serial.print(Vgas,4);
  Vgas0 = 0.97;     // Need to get from 0 ppm Calibration Environment; now given as Vref+Voff
  float h2s = (Vgas-Vgas0)*(70.4075);
  Serial.print("\t");
  Serial.print("H2S ppm: ");
  if(h2s < 0.0)
    h2s *= -1.0;
  Serial.println(h2s,3);
  publish_data(h2s, "h2s");

  /*=========================================
  4. CO Sense  TGS-5042
  Sensitivity : 1.59nA/ppm
  Is = (Vout - 1.00) / 3.13
  ==========================================*/
  adc_result = zadcs147.ADC_readch(co_ch);
  Serial.print(adc_result);
  Serial.print("\t");
  float co = (float)(adc_result * STEPSIZE);
  Serial.print("Vgas:");
  Serial.print(co,4);
  co = (co - 0.00)/3.13;   // Is
  co = co/1.59;  // ppm            // scaling may require from nA to uA 
  Serial.print("\t CO ppm: ");
  if(co < 0.0)
    co *= -1.0;
  Serial.println(co,3);
  publish_data(co, "co");  
  
  /*=========================================
  5. SO2 Sense FECS43-20
  Is= ((VOUT[Gas] - VOUT[Air]) / I-V conversion amp. factor) x 106
  Sensitivity : 500nA(+/-100nA) per ppm ;  0-20ppm range  
  ==========================================*/
  adc_result = zadcs147.ADC_readch(so2_ch);
  Serial.print(adc_result);
  Vgas = (float)(adc_result * STEPSIZE);
  Serial.print("\t Vgas: ");
  Serial.print(Vgas,4);
  Vgas0 = 0.001;     // Calibration Reference @ 0ppm 
  float so2 = ((Vgas - Vgas0)/200000)*10E6;   // in uA
  so2 = (so2 / 0.5)*0.01;   // 
  so2 = so2*1000;
  Serial.print("\t");
  Serial.print("SO2 ppb: ");
  if(so2 < 0.0)
    so2 *= -1.0;
  Serial.println(so2,3);
  publish_data(so2, "so2");  

  /*=========================================
  6. Ozone Sense MQ131
  valueRL = 1Mohm
  ==========================================*/
  adc_result = zadcs147.ADC_readch(oz_ch);
  Serial.print(adc_result);
  float vRL = (float)(adc_result * STEPSIZE);
  float rs = (5.0/vRL - 1.0)* 1000000;   // RL = 1Mohm
  Serial.print("\t Rs: ");
  Serial.print(rs,4);
  // Compute the ratio Rs/R0 and apply the environmental correction
  float valueR0 = 498000;    // Rs value for calibration value at 0 ppm
  float ratio = rs / valueR0 * getEnvCorrectRatio(humidity,temperature);
  // R^2 = 0.9985
  // Use this if you are monitoring low concentration of O3 (air quality project)
  //float ozone = (8.1399 * pow(ratio, 2.3297));
  float ozone = (8.1399 * pow(ratio, 2.3297));
  Serial.print("\t");
  Serial.print("Ozone ppb: ");
  if(ozone < 0.0)
    ozone *= -1.0;
  Serial.println(ozone,3);
  publish_data(ozone, "ozone");
  
  //7. Methane Sense
  adc_result = zadcs147.ADC_readch(met_ch);
  Serial.print(adc_result);
  vRL = (float)(adc_result * STEPSIZE);
  rs = (5.0/vRL - 1.0)* 1000;   // RL = 1Kohm
  Serial.print("\t Rs:");
  Serial.print(rs,4);
  Serial.print("\t");
  valueR0 = 18062.14;                    // Calibration Value at 0 methane
  float methane = rs/valueR0;
  Serial.print("Methane ppm: ");
  if(methane < 0.0)
    methane *= -1.0;
  Serial.println(methane,3);
  publish_data(methane, "methane"); 
  
  //8. Ammonia Sense
  adc_result = zadcs147.ADC_readch(amm_ch);
  Serial.print(adc_result);
  vRL = (float)(adc_result * STEPSIZE);
   rs = (5.0/vRL - 1.0)* 1000;   // RL = 1Kohm
  Serial.print("\t Rs:");
  Serial.print(rs,4);
  Serial.print("\t"); 
  valueR0 = 46107.59;               // Calibration Value at 0 ammonium
  float amm = rs/valueR0;
  Serial.print("Ammonia ppm: ");
  if(amm < 0.0)
    amm *= -1.0;
  Serial.println(amm,3);
  publish_data(amm, "ammonia");
  
  //9. DHT11 Humidity & Temp
  sensors_event_t event;
  dht.temperature().getEvent(&event);
  if (isnan(event.temperature)) {
    Serial.println("Error reading temperature!");
  }
  else {
    Serial.print("DHT Temperature: ");
    temperature = event.temperature;
    Serial.print(temperature);
    Serial.println(" *C");
  }
  
  // Get humidity event and print its value.
  dht.humidity().getEvent(&event);
  if (isnan(event.relative_humidity)) {
    Serial.println("Error reading humidity!");
  }
  else {
    Serial.print("Humidity: ");
    humidity = event.relative_humidity;
    Serial.print(humidity);
    Serial.println("%");
  }
  Serial.println("\n");
  publish_data(humidity);
  
  //10. CO2 Sensor
  int val = co2Sensor.read();
  Serial.print("CO2 value: ");
  Serial.println(val);
  publish_data(val, "humidity");

  
  // DELAY FOR 10 MINUTES
  //  ESP.deepSleep(60*1000*1000);  // ESP Hardware Deepsleep for power saving.
  delay(60e3);
}



/**
 * Get correction to apply on Rs depending on environmental
 * conditions
 */
float getEnvCorrectRatio(float humidityPercent,float temperatureCelsuis) {
   // Select the right equation based on humidity
  // If default value, ignore correction ratio
  if(humidityPercent == 60 && temperatureCelsuis == 20) {
    return 1.0;
  }
  // For humidity > 75%, use the 85% curve
  if(humidityPercent > 75) {
    // R^2 = 0.9986
    return -0.0141 * temperatureCelsuis + 1.5623;
  }
  // For humidity > 50%, use the 60% curve
  if(humidityPercent > 50) {
    // R^2 = 0.9976
    return -0.0119 * temperatureCelsuis + 1.3261;
  }

  // Humidity < 50%, use the 30% curve
  // R^2 = 0.996
  return -0.0103 * temperatureCelsuis + 1.1507;
 }

void publish_data(float value, char* name){
  String payload = "{\"value\":\"";
  payload += value;
  payload += "\"}";

  if (client.publish("iot-2/evt/" + name + "/fmt/json", (char*) payload.c_str())) {
      Serial.println("Published");
  } else {
      Serial.println("Publish Failed");
  }
  Serial.print("Heap: "); Serial.println(ESP.getFreeHeap()); //Low heap can cause problems
}

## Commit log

2021-08-01 Updated Project files
    [SensorMux_v1.0.brd, SensorMux_v1.0.sch]
2021-08-05 Added Node-Red Flows
2021-08-06 Updated Description on Polmo Hardware Readme. Added Rural Sensor node dataflow
2021-08-06 Added Urban Node details and Data flow
2021-08-06 Added details and Data flow about indoor nodes

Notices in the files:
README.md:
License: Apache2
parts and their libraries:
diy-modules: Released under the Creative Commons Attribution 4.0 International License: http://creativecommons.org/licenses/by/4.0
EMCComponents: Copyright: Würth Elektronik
